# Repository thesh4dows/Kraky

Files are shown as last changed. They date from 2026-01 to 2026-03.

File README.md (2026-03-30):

# Kraky

Kraky is a DIY open-hardware project inspired by the Flipper Zero. It uses affordable parts and focuses on an educational, modular, and easy to repair aspect.

I started this journey with just a sketchbook and a lot of passion. The first thing i did was look up all the components and make a list, so i would have a clear path for the next steps.
Then i've done the elettric schematic, once i redacted all the components i started with the elettric schematic and connecting all the components to outline the scheme for the PCB.
Once i've connected all the components i've moved on making the PCB, making the PCB was easy because all the connections where there the only problem was not get tangled in that mess but i've succeded.
With all the elettronics sorted out i moved on with the CAD and firmware, and even if they are a bit rought i'm looking forward to improving them.

For the assemble I suggest putting first the TP4056 and the U.FL connector, because they are smd soldered, and then I suggest putting the RFM98W-433S2, because is the module with the smallest pins, and the you can decide freely the order of the soldering from now on, you can also decide to use some header pins so you can use the modules in other projects.

---

## Main Components

| Function | Component |
|---|---|
| Logic board / Wi-Fi / Bluetooth | **ESP32-S3** |
| Sub-GHz | **RFM98W-433S2** |
| RFID | **RDM6300** |
| NFC | **PN532** |
| Battery charger | **TP4056** |
| Battery | **1000 mAh Li-ion** |
| IR Receiver | **TSOP38238** |
| IR Transmitter | **IR LED** |
| Speaker | **Passive** |
| GPIO Expansion | **10 Female GPIO pins** |
| microSD Slot | **CM1624** *(not yet implemented in PCB)* |
| Buttons | **4 tactile buttons** |
| Oscilloscope | **MPU6050** |
| Display | **Oled Display** |

---

## Future Features 

- microSD support
- new pcb more small
- modularity

---

## WIRING DIAGRAM



---

## PCB 



---

## PCB AND 3D RENDER COMBINED

Immagine 2026-01-27 175736

---

## BOM LIST
| Component | Link |
|---|---|
| **ESP32-S3** | [Aliexpress](https://it.aliexpress.com/item/1005009962649997.html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) |
| **RFM98W-433S2** | [Aliexpress](https://it.aliexpress.com/item/1005008889705168.html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) |
| **RDM6300** | [Aliexpress](https://it.aliexpress.com/item/32878097013.html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) |
| **PN532** | [Aliexpress](https://it.aliexpress.com/item/1005008554785133.html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) |
| **TP4056** | [Aliexpress](https://it.aliexpress.com/item/1005006520142503.html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) |
| **Battery** | [Aliexpress](https://it.aliexpress.com/item/1005006284232365.html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) |
| **TSOP38238** | [Aliexpress](https://it.aliexpress.com/item/32949322622.html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) |
| IR LED | [Aliexpress](https://it.aliexpress.com/item/1005006286672244.html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) |
| Speaker | [Aliexpress](https://it.aliexpress.com/item/1005008743722885.html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) |
| 10 Female GPIO pins | [Aliexpress](https://it.aliexpress.com/item/1005008966856219.html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) |
| **10pF** | [Aliexpress](https://it.aliexpress.com/item/4001146250895.html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) |
| Buttons | [Aliexpress](https://it.aliexpress.com/item/1005003751942617.html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) |
| MPU6050 | [Aliexpress](https://it.aliexpress.com/item/1005010057794277.html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) |
| **100nF** | [Aliexpress](https://it.aliexpress.com/item/1005005691676032.html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) |
| **Battery connector** | [Aliexpress](https://it.aliexpress.com/item/1005009883885132.html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) |
| **2N3904** | [Aliexpress](https://it.aliexpress.com/item/1005009725419981.html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) |
| **BLM21PG331SN1D** | [Aliexpress](https://it.aliexpress.com/item/1005011660929872.html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) | 
| **Antenna** | [Aliexpress](https://www.aliexpress.com/item/1005007502415094.html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) |
| **1K ohm** | [Aliexpress](https://it.aliexpress.com/item/1005008049421850.html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) |
| **10K ohm** | [Aliexpress](https://it.aliexpress.com/item/1005008049421850.html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) |
| **100 ohm** | [Aliexpress](https://it.aliexpress.com/item/1005008049421850.html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) |
| **Oled Display** | [Aliexpress](https://it.aliexpress.com/item/1005009180825215.html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) |
| **Led** | [Aliexpress](https://it.aliexpress.com/item/1005006463058075.html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) |
| **Step Up** | [Aliexpress](https://it.aliexpress.com/item/1005010399811030.html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) |
| **Switch** | [Aliexpress](https://it.aliexpress.com/item/1005004402594340.html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) |
| **U.FL connector** | [Aliexpress](https://www.aliexpress.com/item/4001125536245.html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) |

---

## Responsible Use

Kraky is built to make it easier for anyone to explore and understand how multifunction electronic devices work in everyday life.
It’s not intended for bypassing security systems or breaking any laws.

All features are implemented with an educational and experimental focus.

---

## Tools Used

- KiCad 9
- Fusion360
- PlatformIO

---

## Project Status

This project is **work in progress (WIP)**.  
Future updates will include:

- microSD implementation
- firmware development
- smaller PCB and SMD soldered components 

---

## Contributing

Kraky is an **open and educational project**.  
Feedback, suggestions, and improvements are always welcome.

---

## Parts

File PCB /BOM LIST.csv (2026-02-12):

Component | link | quantity | price
ESP32-S3 | https://it.aliexpress.com/item/1005009962649997.html?mp=1 | 1 | 7,33 €
RFM98W-433S2 | https://it.aliexpress.com/item/1005008889705168.html?mp=1 | 1 | 13,69 €
RDM6300 | https://it.aliexpress.com/item/32878097013.html?mp=1 | 1 | 3,16 €
PN532 | https://it.aliexpress.com/item/1005008554785133.html?mp=1 | 1 | 3,34 €
TP4056 | https://it.aliexpress.com/item/1005006520142503.html?curPageLogUid=HOVHMltfnK6x | 1 | 4,34 €
Battery | https://it.aliexpress.com/item/1005006284232365.html?mp=1 | 1 | 10,09 €
TSOP38238 | https://it.aliexpress.com/item/32949322622.html?mp=1 | 1 | 2,24 €
IR LED | https://it.aliexpress.com/item/1005006286672244.html?curPageLogUid=ph7sqTJjqLZk | 1 | 1,24 €
Speaker | https://it.aliexpress.com/item/1005008743722885.html?mp=1 | 1 | 2,07 €
Female GPIO pins | https://it.aliexpress.com/item/1005008966856219.html?curPageLogUid=SOrvoxlj0a91 | 1 | 1,21 €
10 pF | https://it.aliexpress.com/item/4001146250895.html?curPageLogUid=z2f4APj81CW1 | 1 | 1,51 €
Buttons | https://it.aliexpress.com/item/1005003751942617.html?curPageLogUid=h3YPZfgd06kE | 4 | 2,32 €
MPU6050 | https://it.aliexpress.com/item/1005010057794277.html?mp=1 | 1 | 1,89 €
100 nF | https://it.aliexpress.com/item/1005005691676032.html?mp=1 | 8 | 1,31 €
Battery connector | https://it.aliexpress.com/item/1005009883885132.html?mp=1 | 1 | 1,92 €
2N3904 | https://it.aliexpress.com/item/1005009725419981.html?mp=1 | 1 | 1,89 €
BLM21PG331SN1D | https://it.aliexpress.com/item/1005011660929872.html?curPageLogUid=IwbgsjoqIVvt | 1 | 0,45€+4.25€
Antenna | https://www.aliexpress.com/item/1005007502415094.html?mp=1 | 2 | 1,47€x2
1K ohm | https://it.aliexpress.com/item/1005008049421850.html?curPageLogUid=0AoDAOfCkDU4 | 2 | 1,29 €
10k ohm | https://it.aliexpress.com/item/1005008049421850.html?curPageLogUid=0AoDAOfCkDU4 | 4 | 1,33 €
100 ohm | https://it.aliexpress.com/item/1005008049421850.html?curPageLogUid=0AoDAOfCkDU4 | 1 | 1,34 €
Oled display | https://it.aliexpress.com/item/1005009180825215.html?curPageLogUid=jkERcBiiep5C | 1 | 3,06 €
Led | https://it.aliexpress.com/item/1005006463058075.html?curPageLogUid=CU7YloDPjo8Z | 1 | 1,17 €
Step up | https://it.aliexpress.com/item/1005010399811030.html?curPageLogUid=LqlJv6SQeazs | 1 | 2,54 €
Switch | https://it.aliexpress.com/item/1005004402594340.html?curPageLogUid=7JLAO8Dg6auy | 1 | 1,87 €
u.fl connector | https://www.aliexpress.com/item/4001125536245.html?mp=1 | 1 | 1,90 €

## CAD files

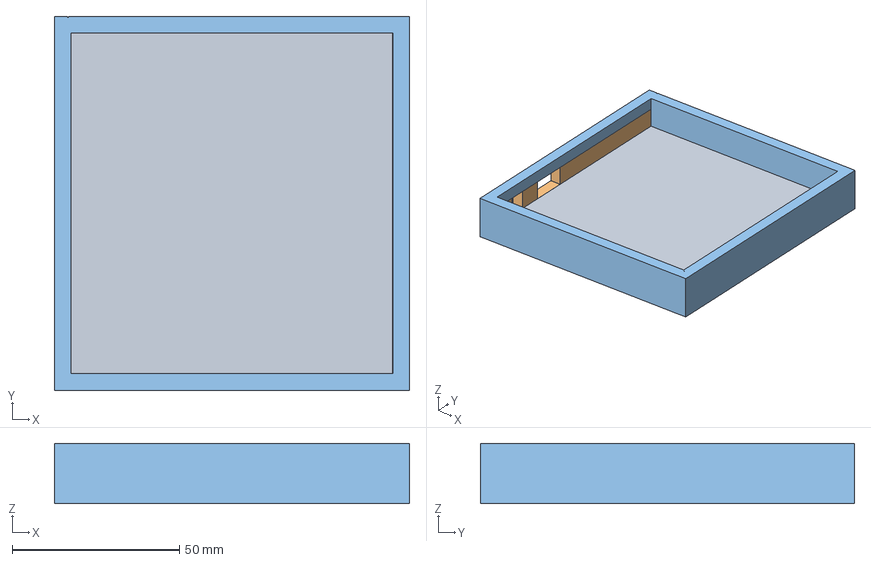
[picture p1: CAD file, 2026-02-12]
3D renders/3D render_.3mf
106.2 x 111.9 x 18.0 mm
Corpo18
Corpo22
Corpo25

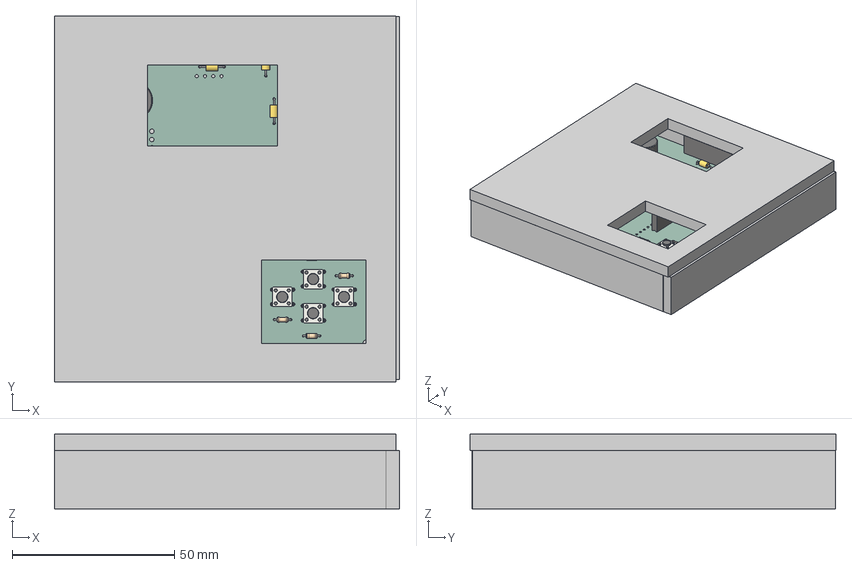
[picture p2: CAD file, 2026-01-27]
3D renders/kraky.step
106.2 x 112.5 x 23.0 mm
R_Axial_DIN0204_L3.6mm_D1.6mm_P5.08mm_Horizontal x 7
SW_PUSH_6mm x 4
C_Axial_L3.8mm_D2.6mm_P7.50mm_Horizontal x 9
R_0805_2012Metric
PinSocket_1x08_P2.54mm_Vertical
LED_D5.0mm x 2
PinSocket_1x10_P2.54mm_Vertical
JST_EH_B2B-EH-A_1x02_P2.50mm_Vertical
SW_Slide_SPDT_Angled_CK_OS102011MA1Q
MagneticBuzzer_ProSignal_ABT-410-RC
TO-92_Inline
PCB_Body
Pads
IC
Caps
Resisroes
PinHeaders
PinSocket
kraky_PCB

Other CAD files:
3D renders/kraky.f3d

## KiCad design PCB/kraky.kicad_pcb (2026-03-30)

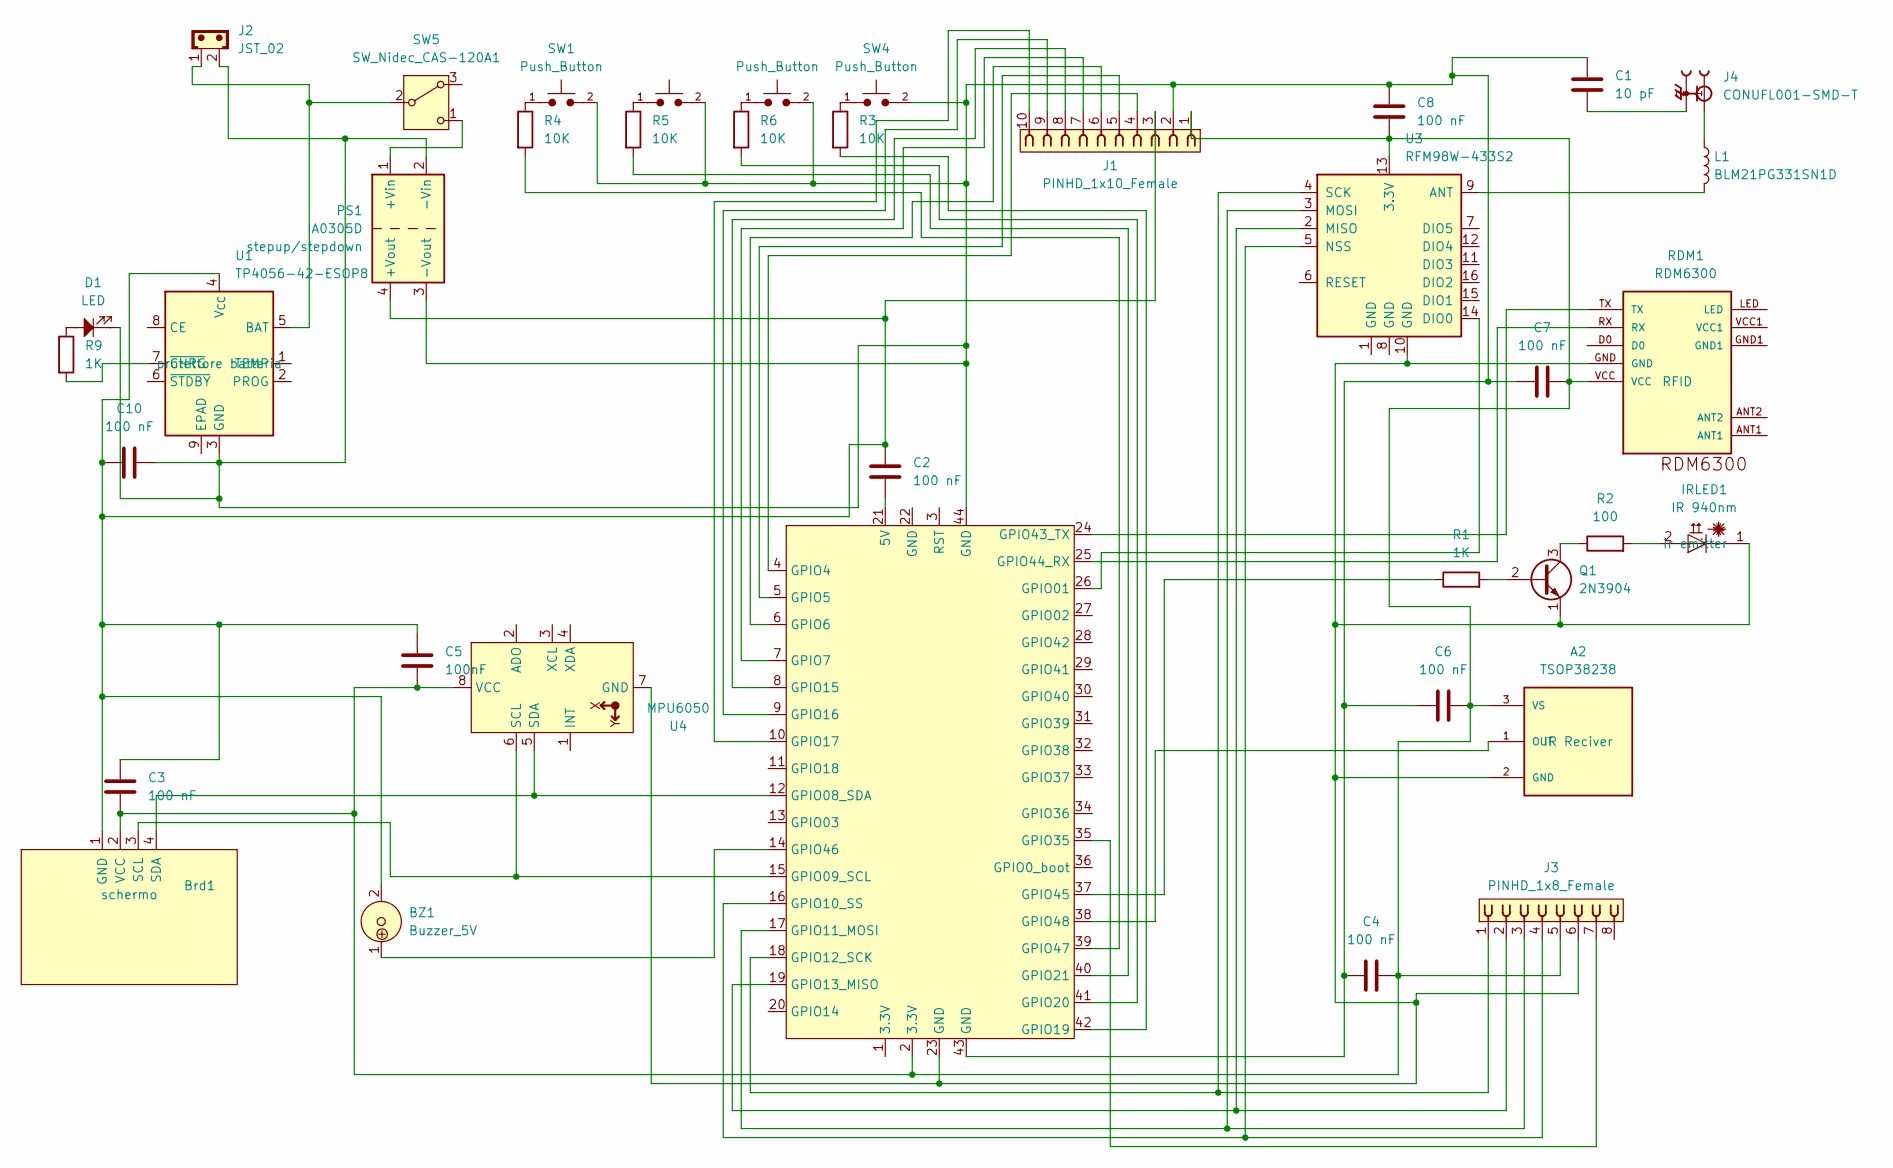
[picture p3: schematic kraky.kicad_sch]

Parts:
A2: TSOP38238; XDCR_TSOP38238; PARTREV 1.7
BZ1: Buzzer_5V; MagneticBuzzer_ProSignal_ABT-410-RC
Brd1: SSD1306; 128x64OLED
C1: 10 pF; C_Axial_L3.8mm_D2.6mm_P7.50mm_Horizontal
C2, C3, C4, C6, C7, C8, C10: 100 nF; C_Axial_L3.8mm_D2.6mm_P7.50mm_Horizontal
C5: 100nF; C_Axial_L3.8mm_D2.6mm_P7.50mm_Horizontal
D1: LED; LED_D5.0mm
IRLED1: IR 940nm; LED_D5.0mm
J1: PINHD_1x10_Female; PinSocket_1x10_P2.54mm_Vertical
J2: JST_02; JST_EH_B2B-EH-A_1x02_P2.50mm_Vertical
J3: PINHD_1x8_Female; PinSocket_1x08_P2.54mm_Vertical
J4: CONUFL001-SMD-T; LINX_CONUFL001-SMD-T
L1: BLM21PG331SN1D; R_0805_2012Metric
PS1: IA0305D; step up kraky
Q1: 2N3904; TO-92_Inline
R1, R9: 1K; R_Axial_DIN0204_L3.6mm_D1.6mm_P5.08mm_Horizontal
R2: 100; R_Axial_DIN0204_L3.6mm_D1.6mm_P5.08mm_Horizontal
R3, R4, R5, R6: 10K; R_Axial_DIN0204_L3.6mm_D1.6mm_P5.08mm_Horizontal
RDM1: RDM6300
SW1, SW2, SW3, SW4: Push_Button; SW_PUSH_6mm
SW5: SW_Nidec_CAS-120A1; SW_Slide_SPDT_Angled_CK_OS102011MA1Q
U1: TP4056-42-ESOP8; SOIC-8-1EP_3.9x4.9mm_P1.27mm_EP2.41x3.3mm_ThermalVias
U2: esp32-s3
U3: RFM98W-433S2; HOPERF_RFM9XW_THT
U4: MPU6050; MPU6050_Breakout

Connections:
unnamed: A2.2 (GND), IRLED1.1 (C), J3.6, Q1.1 (E), RDM1.GND, U2.23 (GND), U3.10 (GND), U4.7 (GND)
unnamed: A2.1 (OUT), U2.38 (GPIO48)
unnamed: A2.3 (VS), Brd1.2 (VCC), C3.2, C4.1, C5.2, C6.1, C7.1, C8.2, J1.1, J3.5, RDM1.VCC, U2.2 (3.3V), U3.13 (3.3V), U4.8 (VCC)
unnamed: BZ1.2, Brd1.1 (GND), C2.1, C3.1, C5.1, C10.1, J1.3, PS1.4 (+Vout), U1.4 (V_{CC})
unnamed: Brd1.3 (SCL), U2.15 (GPIO09_SCL), U4.6 (SCL)
unnamed: Brd1.4 (SDA), U2.12 (GPIO08_SDA), U4.5 (SDA)
unnamed: C1.2, J4.2, J4.3
unnamed: D1.2, R9.1
unnamed: IRLED1.2 (A), R2.2
unnamed: J4.1, L1.1
unnamed: PS1.1 (+Vin), SW5.1 (C)
unnamed: C1.1, C4.2, C6.2, C7.2, C8.1, C10.2, D1.1, J1.2, J2.2, PS1.2 (-Vin), PS1.3 (-Vout), SW1.2, SW2.2, SW3.2, SW4.2, U1.3 (GND), U2.43 (GND), U2.44 (GND)
unnamed: Q1.2 (B), R1.2
unnamed: Q1.3 (C), R2.1
unnamed: R3.1, SW4.1
unnamed: R4.1, SW1.1
unnamed: R5.1, SW2.1
unnamed: R6.1, SW3.1
unnamed: J2.1, SW5.2 (B), U1.5 (BAT)
unnamed: R9.2, U1.7 (~CHRG)
unnamed: C2.2, U2.21 (5V)
unnamed: U2.26 (GPIO01), U3.14 (DIO0)
unnamed: J1.4, U2.4 (GPIO4)
unnamed: J1.5, U2.5 (GPIO5)
unnamed: J1.6, U2.6 (GPIO6)
unnamed: J1.7, U2.7 (GPIO7)
unnamed: J3.4, U2.16 (GPIO10_SS), U3.5 (NSS)
unnamed: J3.3, U2.17 (GPIO11_MOSI), U3.3 (MOSI)
unnamed: J3.1, U2.18 (GPIO12_SCK), U3.4 (SCK)
unnamed: J3.2, U2.19 (GPIO13_MISO), U3.2 (MISO)
unnamed: J1.8, U2.8 (GPIO15)
unnamed: J1.9, U2.9 (GPIO16)
unnamed: J1.10, U2.10 (GPIO17)
unnamed: R3.2, U2.42 (GPIO19)
unnamed: R6.2, U2.41 (GPIO20)
unnamed: R5.2, U2.40 (GPIO21)
unnamed: J3.7, U2.35 (GPIO35)
unnamed: RDM1.TX, U2.24 (GPIO43_TX)
unnamed: RDM1.RX, U2.25 (GPIO44_RX)
unnamed: R1.1, U2.37 (GPIO45)
unnamed: BZ1.1, U2.14 (GPIO46)
unnamed: R4.2, U2.39 (GPIO47)
unnamed: L1.2, U3.9 (ANT)

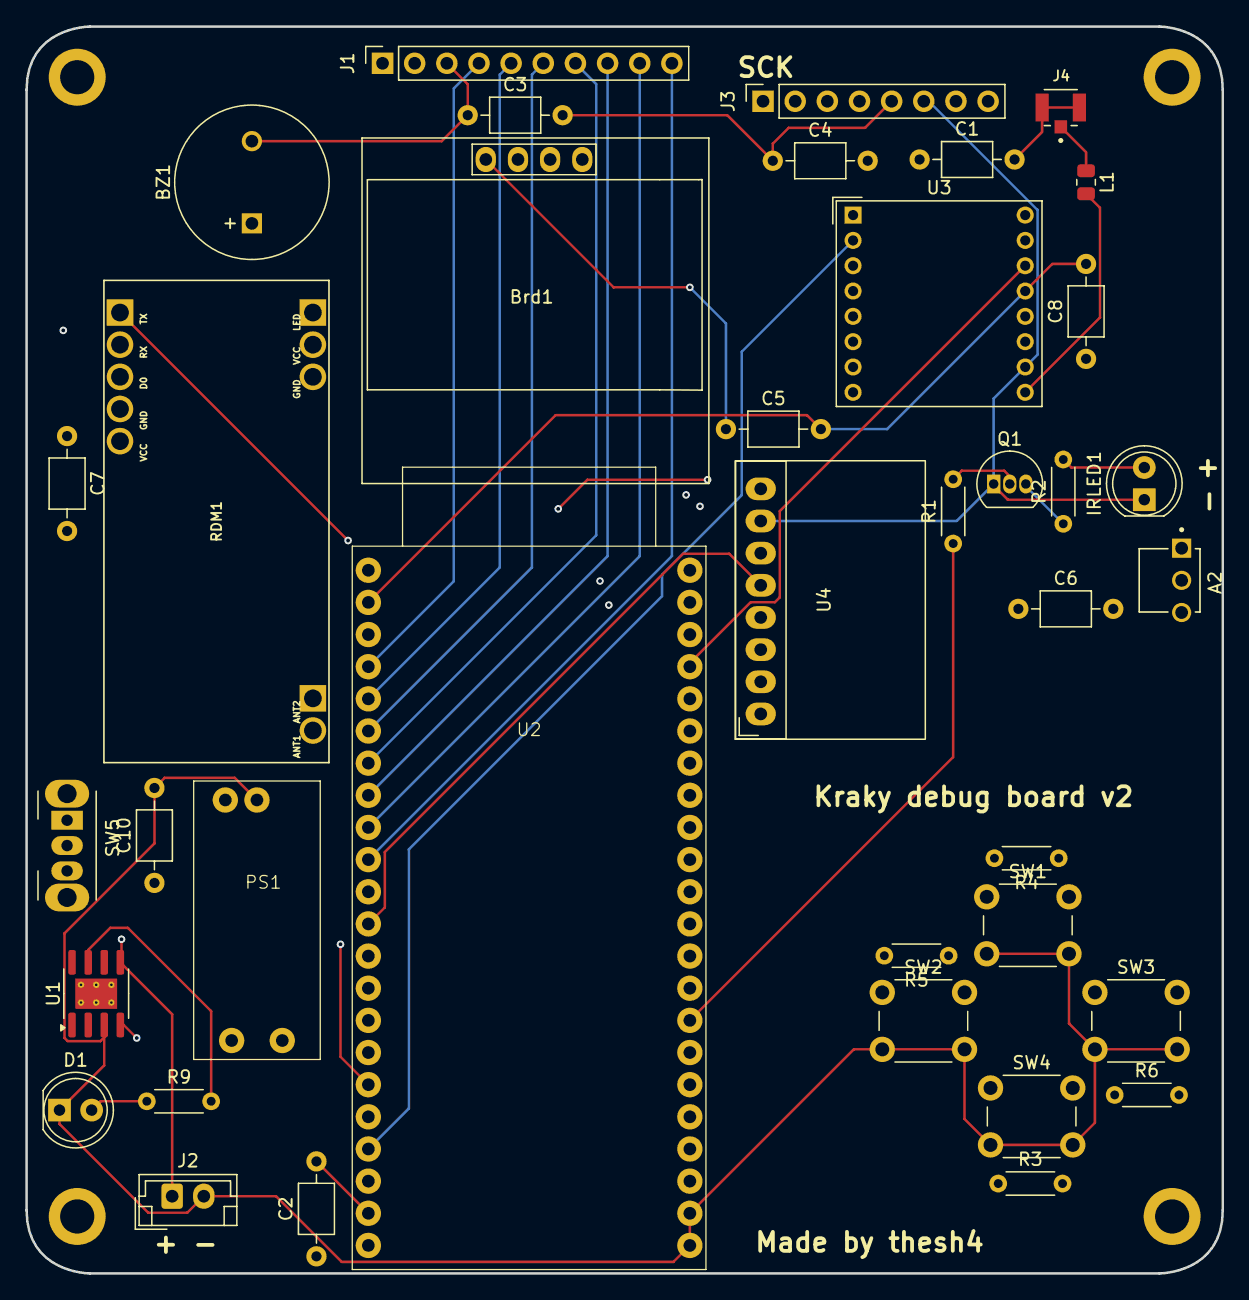
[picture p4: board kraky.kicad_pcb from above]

Board: 4 copper layers, 94.5 x 98.5 mm, 42 parts (0 on the bottom side), 43 nets.

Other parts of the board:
buco1, buco2, buco3, buco4: MountingHole_2.7mm_M2.5_ISO14580_Pad

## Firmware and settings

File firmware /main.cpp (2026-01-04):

/*
 * KRAKY DEVICE – ESP32
 */

#include <Arduino.h>
#include <WiFi.h>
#include <Wire.h>
#include <SPI.h>
#include <Adafruit_SSD1306.h>
#include <Adafruit_PN532.h>
#include <IRremoteESP8266.h>
#include <IRrecv.h>
#include <IRsend.h>
#include <IRutils.h>
#include <LoRa.h>

// ================= PIN =================

// Pulsanti
#define BTN_UP     5
#define BTN_DOWN   18
#define BTN_OK     19
#define BTN_BACK   25

// OLED
#define OLED_SDA   21
#define OLED_SCL   22

// Buzzer
#define BUZZER     13

// RFID RDM6300 (Serial2)
#define RFID_RX    17
#define RFID_TX    4

// IR
#define IR_RX      35
#define IR_TX      16

// SPI (VSPI)
#define SPI_SCK    18
#define SPI_MISO   19
#define SPI_MOSI   23

// PN532
#define NFC_SS     5

// LoRa
#define LORA_SS    26
#define LORA_RST   27
#define LORA_DIO0  14

// ================= OGGETTI =================

Adafruit_SSD1306 display(128, 64, &Wire, -1);
Adafruit_PN532 nfc(NFC_SS);

IRrecv irRecv(IR_RX);
IRsend irSend(IR_TX);
decode_results irResults;

// ================= MENU =================

const char *menuItems[] = {
  "RFID Reader",
  "NFC Scanner",
  "IR Receiver",
  "LoRa Listener",
  "WiFi Scan",
  "About"
};

uint8_t menuIndex = 0;
const uint8_t MENU_LEN = 6;

// ================= UTILITY =================

void beep(uint16_t freq, uint16_t dur) {
  tone(BUZZER, freq, dur);
  delay(dur);
  noTone(BUZZER);
}

bool pressed(uint8_t pin) {
  return digitalRead(pin) == LOW;
}

void drawText(const char *txt) {
  display.clearDisplay();
  display.setTextSize(1);
  display.setTextColor(SSD1306_WHITE);
  display.setCursor(0, 0);
  display.print(txt);
  display.display();
}

// ================= MENU DISPLAY =================

void drawMenu() {
  display.clearDisplay();
  display.setCursor(0, 0);
  display.println("=== KRAKY ===\n");

  for (uint8_t i = 0; i < MENU_LEN; i++) {
    display.print(i == menuIndex ? "> " : "  ");
    display.println(menuItems[i]);
  }
  display.display();
}

// ================= RFID =================

void scanRFID() {
  Serial2.begin(9600, SERIAL_8N1, RFID_RX, RFID_TX);
  drawText("RFID\nAvvicina il tag");

  char id[16] = {0};
  uint8_t idx = 0;
  unsigned long t0 = millis();

  while (millis() - t0 < 8000) {
    if (Serial2.available()) {
      char c = Serial2.read();
      if (isHexadecimalDigit(c) && idx < 12) {
        id[idx++] = c;
        id[idx] = '\0';
      }
      if (idx >= 12) {
        char buf[32];
        snprintf(buf, sizeof(buf), "TAG RFID:\n%s", id);
        drawText(buf);
        beep(1000, 150);
        delay(3000);
        return;
      }
    }
    if (pressed(BTN_BACK)) break;
  }

  drawText("Nessun TAG");
  delay(2000);
}

// ================= NFC =================

void scanNFC() {
  drawText("NFC\nAvvicina il tag");

  uint8_t uid[7];
  uint8_t uidLen;

  unsigned long t0 = millis();
  while (millis() - t0 < 8000) {
    if (nfc.readPassiveTargetID(PN532_MIFARE_ISO14443A, uid, &uidLen)) {
      display.clearDisplay();
      display.println("NFC UID:");
      for (uint8_t i = 0; i < uidLen; i++) {
        display.print(uid[i], HEX);
        display.print(" ");
      }
      display.display();
      beep(1200, 200);
      delay(3000);
      return;
    }
    if (pressed(BTN_BACK)) break;
  }

  drawText("Nessun NFC");
  delay(2000);
}

// ================= IR =================

void scanIR() {
  drawText("IR\nPremi un tasto");
  irRecv.enableIRIn();

  unsigned long t0 = millis();
  while (millis() - t0 < 10000) {
    if (irRecv.decode(&irResults)) {
      char buf[48];
      snprintf(
        buf,
        sizeof(buf),
        "IR:\n%s\n0x%X",
        typeToString(irResults.decode_type).c_str(),
        irResults.value
      );
      drawText(buf);
      beep(900, 150);
      irRecv.resume();
      delay(3000);
      return;
    }
    if (pressed(BTN_BACK)) break;
  }

  drawText("Nessun IR");
  delay(2000);
}

// ================= LORA =================

void listenLoRa() {
  drawText("LoRa\nIn ascolto...");

  unsigned long t0 = millis();
  while (millis() - t0 < 15000) {
    int size = LoRa.parsePacket();
    if (size) {
      char msg[64];
      uint8_t i = 0;
      while (LoRa.available() && i < sizeof(msg) - 1) {
        msg[i++] = (char)LoRa.read();
      }
      msg[i] = '\0';
      drawText(msg);
      beep(800, 200);
      delay(3000);
      return;
    }
    if (pressed(BTN_BACK)) break;
  }

  drawText("Nessun pacchetto");
  delay(2000);
}

// ================= WIFI =================

void wifiScan() {
  drawText("WiFi scan...");
  WiFi.mode(WIFI_STA);
  WiFi.disconnect();
  delay(200);

  int n = WiFi.scanNetworks();
  display.clearDisplay();
  display.println("Reti trovate:");

  for (int i = 0; i < n && i < 4; i++) {
    display.println(WiFi.SSID(i));
  }
  display.display();
  beep(1000, 200);
  delay(4000);
}

// ================= ABOUT =================

void about() {
  drawText("KRAKY DEVICE\nESP32\nv1.0\nby You <3");
  delay(4000);
}

// ================= SETUP =================

void setup() {
  Serial.begin(115200);

  pinMode(BTN_UP, INPUT_PULLUP);
  pinMode(BTN_DOWN, INPUT_PULLUP);
  pinMode(BTN_OK, INPUT_PULLUP);
  pinMode(BTN_BACK, INPUT_PULLUP);
  pinMode(BUZZER, OUTPUT);

  Wire.begin(OLED_SDA, OLED_SCL);
  display.begin(SSD1306_SWITCHCAPVCC, 0x3C);

  SPI.begin(SPI_SCK, SPI_MISO, SPI_MOSI);

  nfc.begin();
  nfc.SAMConfig();

  LoRa.setPins(LORA_SS, LORA_RST, LORA_DIO0);
  LoRa.begin(433E6);

  drawText("KRAKY BOOT");
  beep(600, 100);
  beep(800, 100);
}

// ================= LOOP =================

void loop() {
  drawMenu();

  if (pressed(BTN_UP)) {
    menuIndex = (menuIndex + MENU_LEN - 1) % MENU_LEN;
    beep(1200, 40);
    delay(200);
  }

  if (pressed(BTN_DOWN)) {
    menuIndex = (menuIndex + 1) % MENU_LEN;
    beep(1200, 40);
    delay(200);
  }

  if (pressed(BTN_OK)) {
    beep(1500, 60);
    switch (menuIndex) {
      case 0: scanRFID(); break;
      case 1: scanNFC(); break;
      case 2: scanIR(); break;
      case 3: listenLoRa(); break;
      case 4: wifiScan(); break;
      case 5: about(); break;
    }
  }

  delay(100);
}

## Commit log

2025-12-18 first version of the electrical diagram
    [esp32prog.kicad_sch]
2025-12-31 third version of the elettric scheme
    [esp32prog.kicad_sch]
2026-01-03 3D render of the Kraky's enclosure
    [kraky.f3d]
2026-01-04 this is the first version of the pcb
    [esp32prog.kicad_pcb]
2026-01-04 this is the third version of the schematich
    [esp32prog.kicad_sch]
2026-01-05 this is the first version of the pcb, it's a debug board
    [esp32prog.kicad_pcb]
2026-01-08 Update and rename esp32prog.kicad_pcb to kraky.kicad_pcb
    [kraky.kicad_pcb]
2026-01-08 Update and rename esp32prog.kicad_sch to kraky.kicad_sch
    [kraky.kicad_sch]
2026-01-08 kraky's gerbers for pcb ordering
2026-01-11 new schematic with change in the esp32
    [kraky.kicad_sch]
2026-01-17 updated, read readme
    [kraky.csv, kraky.kicad_pcb, kraky.kicad_sch]
2026-01-22 added female pins where i would put the PN532 because i couldn't find the library
    [kraky.kicad_pcb, kraky.kicad_sch]
2026-02-12 Rename 3D render_.3mf to 3D renders / 3D render_.3mf
    [3D render_.3mf]
2026-02-12 PCB files
    [BOM LIST.csv]
2026-02-12 Rename kraky.kicad_pro to PCB /kraky.kicad_pro
2026-02-12 3D renders
    [kraky.step]
